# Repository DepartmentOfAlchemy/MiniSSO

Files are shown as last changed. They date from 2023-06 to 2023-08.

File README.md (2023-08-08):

**MiniSSO**

The MiniSSO is a [FeatherWing](https://learn.adafruit.com/adafruit-feather/featherwings) designed for the [Feather](https://learn.adafruit.com/adafruit-feather) ecosystem create by [Adafruit](https://www.adafruit.com). It provides 1 optically isolated input and 2 solid state PWM outputs. The board is designed to be a haunted attraction prop control system. The input is for the prop trigger. And the outputs can drive 12V LED lights and 12V pneumatic solinoids or 12V relays.

**Pinout**
* Isolated input: D13 (Jumper alternative A3)
* PWM output 1: D12 (Jumper alternative A4)
* PWM output 2: D11 (Jumper alternative A5)

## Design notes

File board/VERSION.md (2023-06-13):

## Rev 1
* Initial release

## Rev 2
* Fix silkscreen for label of Output 1. Was previously mislabled as Output 2 making it a duplicate of the real Output 2.

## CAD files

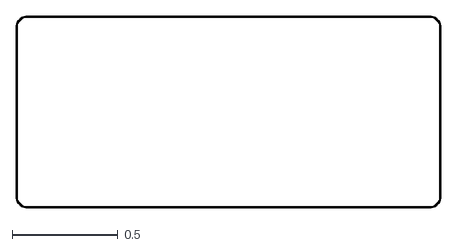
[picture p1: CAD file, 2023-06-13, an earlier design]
board/MiniSSO/MiniSSO-gerbers/Rev1/MiniSSO-Edge_Cuts.dxf
2.00 x 0.904

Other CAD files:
board/MiniSSO/MiniSSO-gerbers/Rev1/MiniSSO-F_Mask.dxf

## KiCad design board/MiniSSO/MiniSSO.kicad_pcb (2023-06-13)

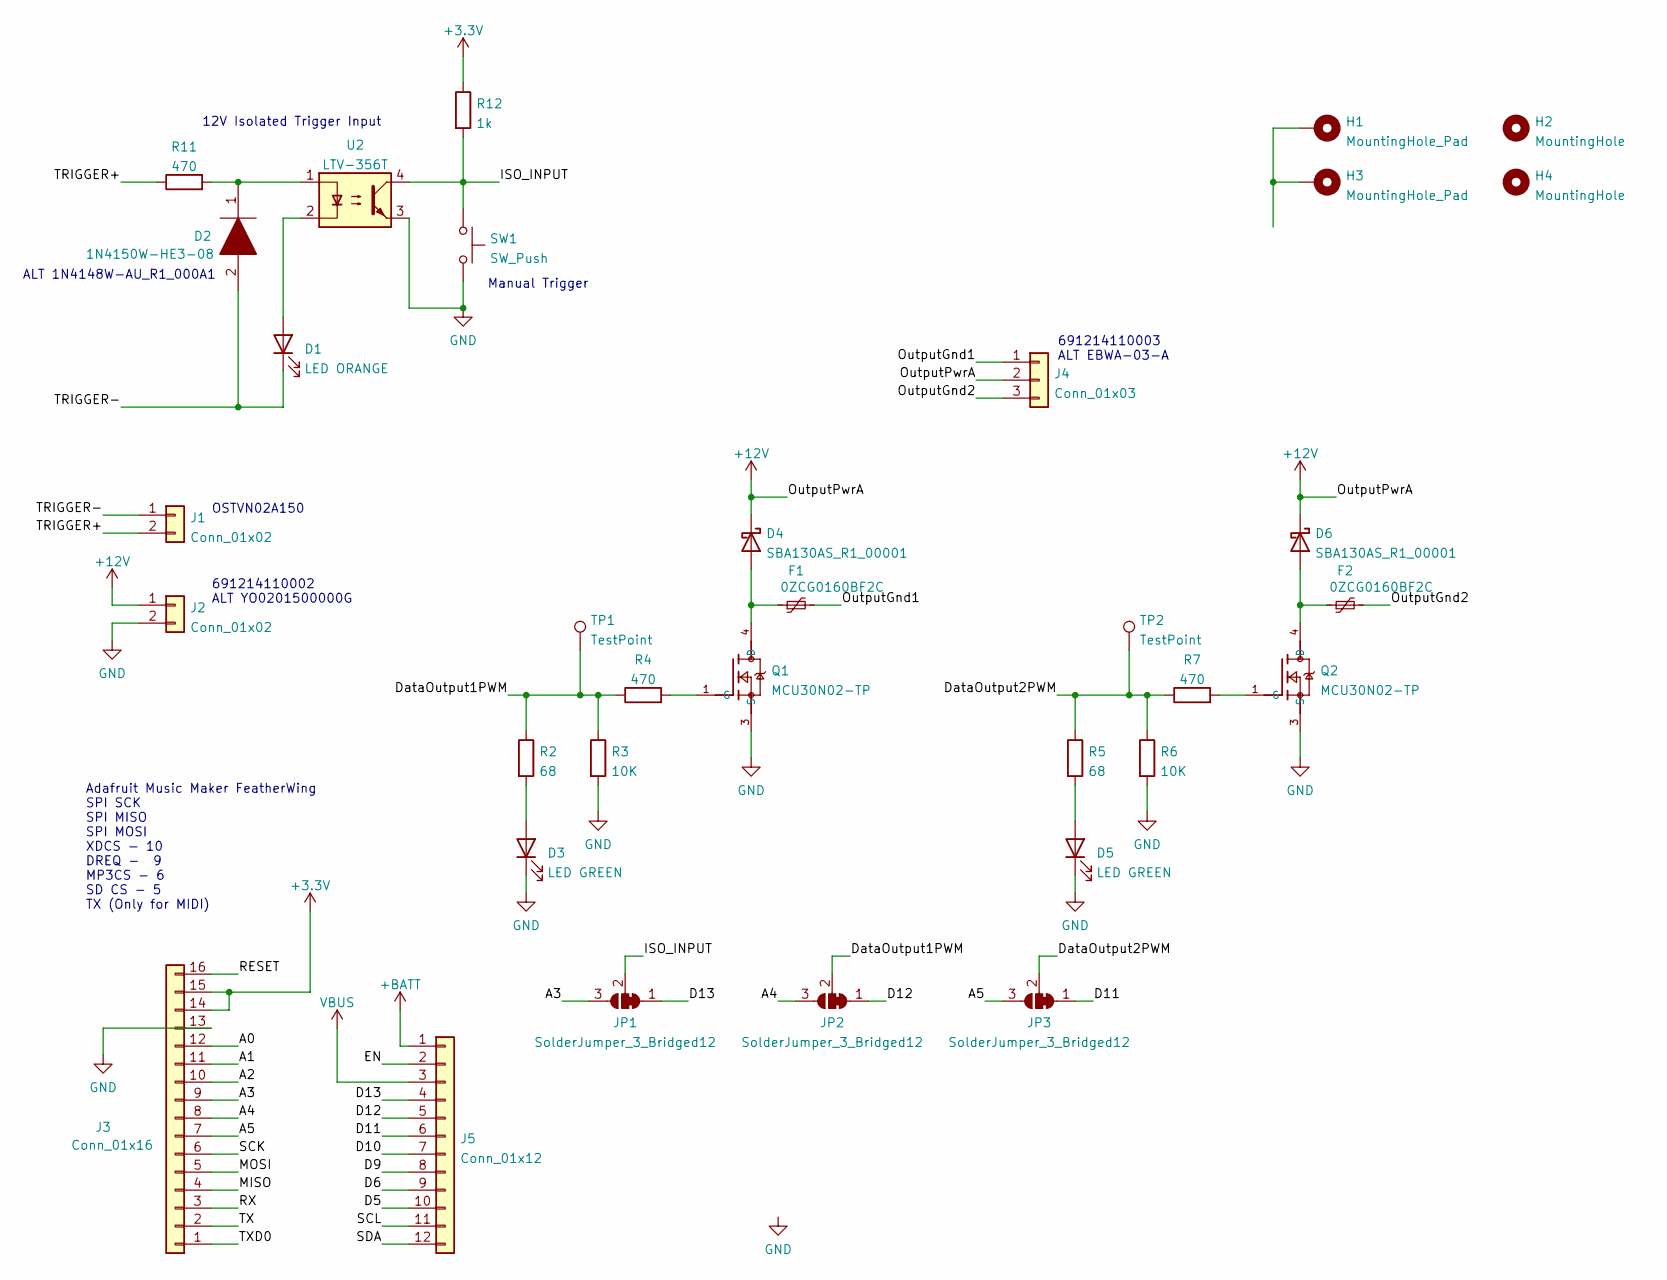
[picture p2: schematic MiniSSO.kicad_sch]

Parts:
D1: LED ORANGE; LED_0603_1608Metric
D2: 1N4150W-HE3-08; D_SOD-123; Manufacturer_Part_Number S1GTR
D3, D5: LED GREEN; LED_0603_1608Metric
D4, D6: SBA130AS_R1_00001; D_SOD-123
F1, F2: 0ZCG0160BF2C; Fuse_1812_4532Metric
H1, H3: MountingHole_Pad; MountingHole_2.7mm_M2.5_ISO14580_Pad
H2, H4: MountingHole; MountingHole_2.7mm_M2.5_ISO14580
J1: Conn_01x02; OSTVN02A150
J2: Conn_01x02; 691214110002
J3: Conn_01x16; PinHeaderPlain_1x16_P2.54mm_Vertical
J4: Conn_01x03; 691214110003
J5: Conn_01x12; PinHeaderPlain_1x12_P2.54mm_Vertical
JP1, JP2, JP3: SolderJumper_3_Bridged12; SolderJumper-3_P1.3mm_Bridged12_RoundedPad1.0x1.5mm
Q1, Q2: MCU30N02-TP; TO229P991X239-3N
R2, R5: 68; R_0603_1608Metric
R3, R6: 10K; R_0603_1608Metric
R4, R7, R11: 470; R_0603_1608Metric
R12: 1k; R_0603_1608Metric
SW1: SW_Push; SW_Push_1P1T_NO_CK_KMR2
TP1, TP2: TestPoint; TestPoint_Pad_D2.5mm
U2: LTV-356T; SO-4_4.4x3.6mm_P2.54mm

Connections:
+3V3: J3.14, J3.15, R12.1
+12V: D4.1 (K), D6.1 (K), J2.1, J4.2
+BATT: J5.1
/A0: J3.12
/A1: J3.11
/A2: J3.10
/A3: J3.9, JP1.3 (B)
/A4: J3.8, JP2.3 (B)
/A5: J3.7, JP3.3 (B)
/D5: J5.10
/D6: J5.9
/D9: J5.8
/D10: J5.7
/D11: J5.6, JP3.1 (A)
/D12: J5.5, JP2.1 (A)
/D13: J5.4, JP1.1 (A)
/DataOutput1PWM: JP2.2 (C), R2.1, R3.1, R4.1, TP1.1
/DataOutput2PWM: JP3.2 (C), R5.1, R6.1, R7.1, TP2.1
/EN: J5.2
/ISO_INPUT: JP1.2 (C), R12.2, SW1.1, U2.4
/MISO: J3.4
/MOSI: J3.5
/OutputGnd1: F1.2, J4.1
/OutputGnd2: F2.2, J4.3
/RESET: J3.16
/RX: J3.3
/SCK: J3.6
/SCL: J5.11
/SDA: J5.12
/TRIGGER+: J1.2, R11.1
/TRIGGER-: D1.1 (K), D2.2, J1.1
/TX: J3.2
/TXD0: J3.1
unnamed: D1.2 (A), U2.2
unnamed: D2.1, R11.2, U2.1
unnamed: D3.2 (A), R2.2
unnamed: D4.2 (A), F1.1, Q1.4 (D)
unnamed: D5.2 (A), R5.2
unnamed: D6.2 (A), F2.1, Q2.4 (D)
unnamed: Q1.1 (G), R4.2
unnamed: Q2.1 (G), R7.2
VBUS: J5.3

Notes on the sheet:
12V Isolated Trigger Input
691214110003 ALT EBWA-03-A
Manual Trigger
Adafruit Music Maker FeatherWing SPI SCK SPI MISO SPI MOSI XDCS - 10 DREQ - 9 MP3CS - 6 SD CS - 5 TX (Only for MIDI)
OSTVN02A150
691214110002 ALT YO0201500000G
ALT 1N4148W-AU_R1_000A1

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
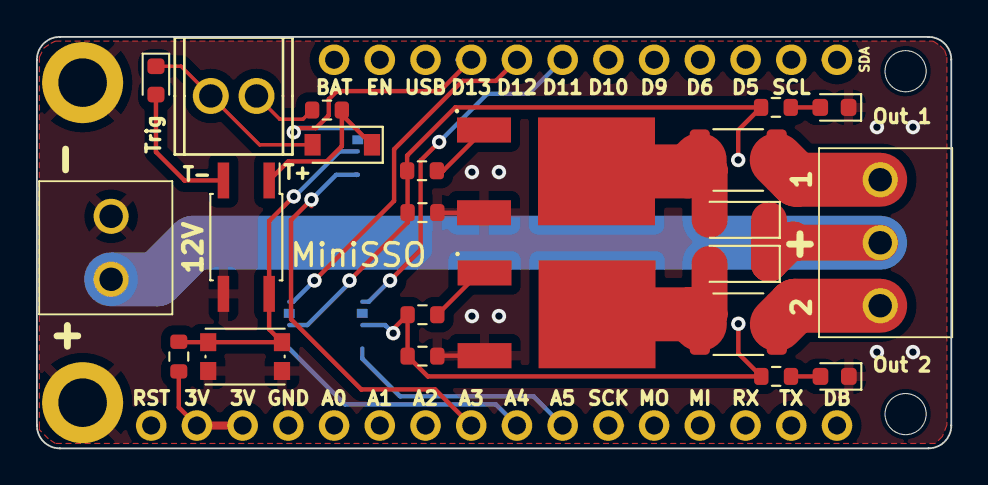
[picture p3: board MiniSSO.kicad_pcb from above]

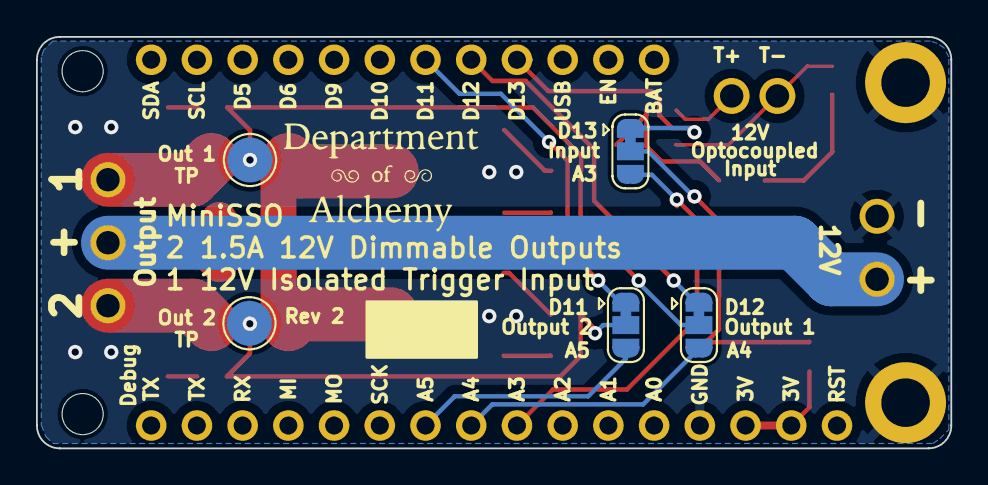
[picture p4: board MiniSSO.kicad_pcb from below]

Board: 2 copper layers, 50.8 x 22.9 mm, 34 parts (5 on the bottom side), 24 nets.

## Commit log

2022-04-11 First complete layout of board. Still need silkscreen documentation.
    [MiniSSO.kicad_pcb, MiniSSO.kicad_sch]
2022-04-17 Rev 1: Initial version of the board.
    [MiniSSO.kicad_pcb, MiniSSO.kicad_sch]
2022-04-17 Rev 1: PCB changed after final zone file and DRC before making gerbers.
    [MiniSSO.kicad_pcb]
2022-04-17 Rev 1: Save gerber output settings.
    [MiniSSO.kicad_pcb]
2022-04-17 Rev 1: Modified trace to solder bridge for input to provide larger ground plane around the solder bridge.
    [MiniSSO.kicad_pcb]
2023-06-13 Revision 2. First production board run.
    [MiniSSO-Edge_Cuts.dxf, MiniSSO-F_Mask.dxf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]
